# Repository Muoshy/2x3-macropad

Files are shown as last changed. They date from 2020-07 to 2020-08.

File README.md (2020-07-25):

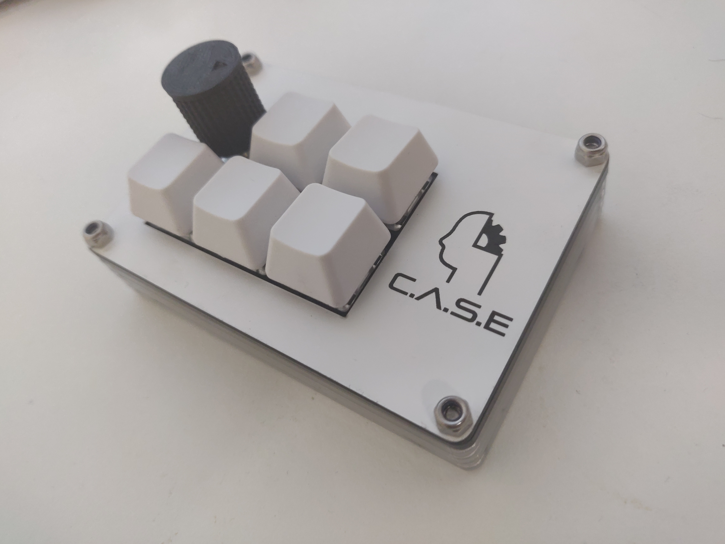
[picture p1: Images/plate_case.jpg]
top


# 2x3 Macropad

Extremely simple 2x3 macropad with sandwich case.

  - QMK firmware
  - Acrylic sandwich case
  - Encoder support
  
## Schematic

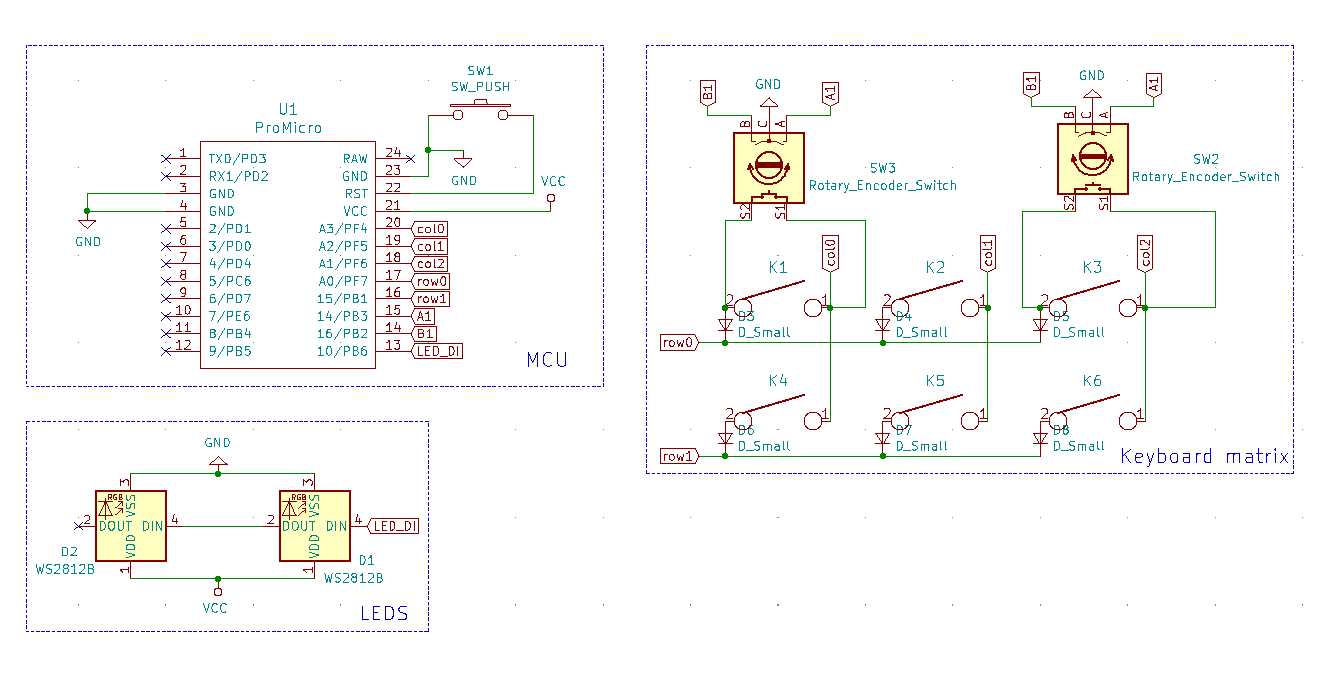
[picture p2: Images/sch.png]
sch


## PCB

## Case
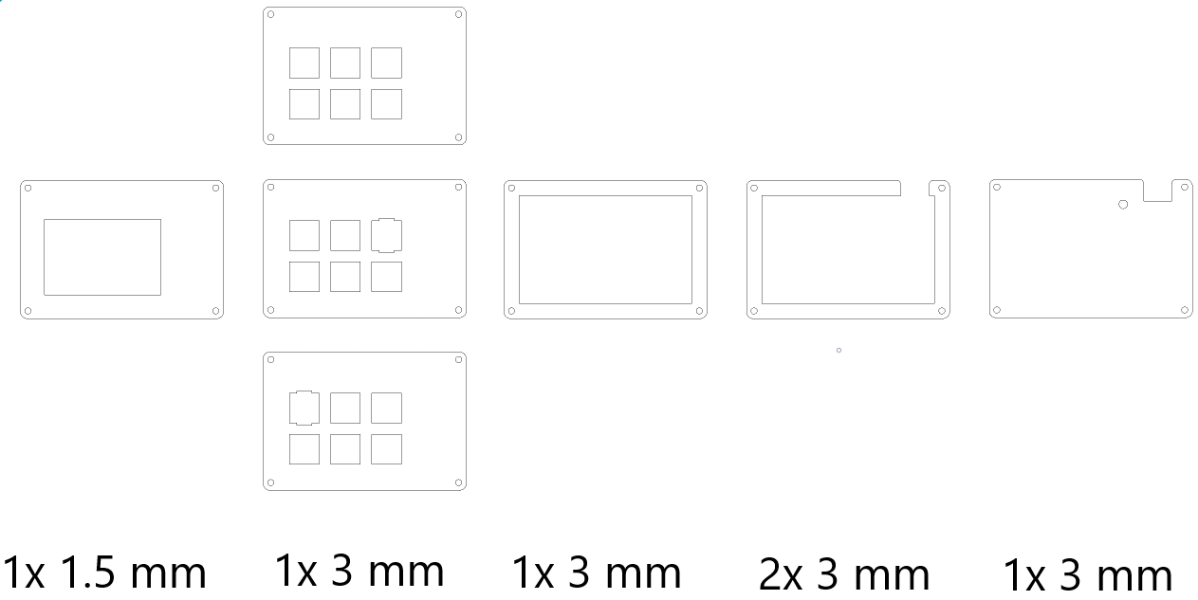
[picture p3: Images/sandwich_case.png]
case

Case plates for laser cutting. 0.15 mm kerf already accounted for in .dxf files.
Choose one of the three switch plates according to your encoder placement. 
For same results as image above, engrave on 2 layer acrylic.

  - 4x M3 20mm screws
  - 4x M3 nuts

## Software
Running on QMK firmware. Use QMK Toolbox to flash with provided HEX file.
Then use VIA configurator to configure keybinds.
For further customization (encoder keycodes), setup a QMK build environment and compile your own HEX files.

## Flashing
  - Download and open QMK Toolbox
  - Select HEX file
  - Choose ATMega32u4 as microcontroller
  - Push reset button on board and then press flash button in toolbox.

## Keybinds
  - Download and install VIA Configurator
  - Open VIA and go to File->Import Keymap
  - Select the keymap.json file
  - Plug in the macropad

## BOM

| Component 		| Quantity 	| Link 								|
|---		|---	|---								|
| MX switches 		| 6x (5x) | 								|
| 1N4148 diodes 		| 6x 	| 								|
| 5.2x5.2mm SMD pushbutton 		| 1x 	| [Mouser](https://www.google.com) 	|
| Arduino Pro Micro 5V 16 MHz | 1x 	| 								|
| WS2812B 		| 2x 	| 								|
| EC11 Encoder 15mm shaft 	| 1x 	| 								|

WS2812B optional as undeglow is not the best on this board due to few LEDs and bad placement.
Only 5 switches needed if also using encoder.

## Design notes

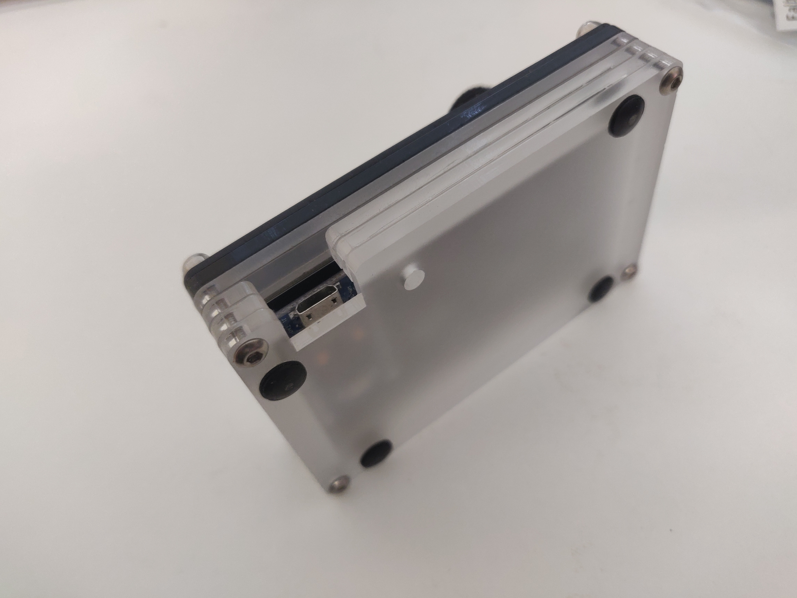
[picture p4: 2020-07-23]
Images/side_view.jpg

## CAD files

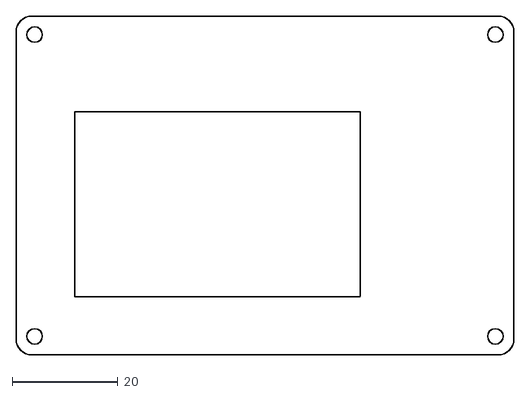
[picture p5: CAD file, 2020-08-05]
Hardware/Sandwich case/#top_plate_engraving.dxf
94.0 x 64.0

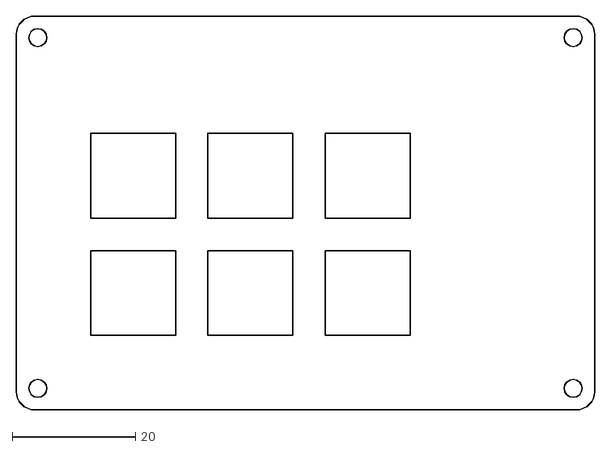
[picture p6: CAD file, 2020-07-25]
Hardware/Sandwich case/switch_plate_no_encoder.dxf
94.0 x 64.0

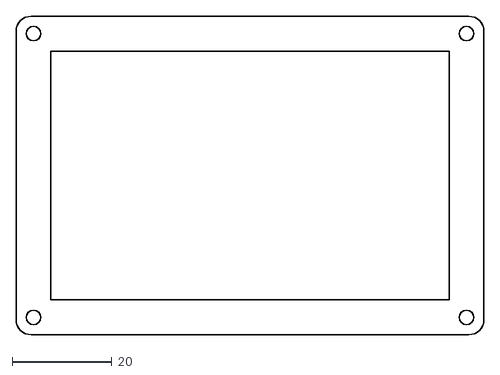
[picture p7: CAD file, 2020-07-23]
Hardware/Sandwich case/middle_plate.dxf
94.0 x 64.0

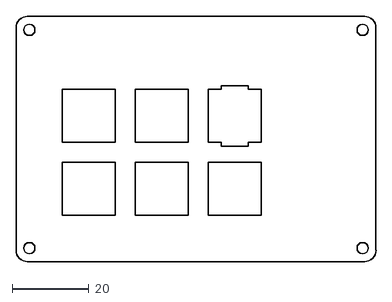
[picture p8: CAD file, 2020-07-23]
Hardware/Sandwich case/switch_plate_right_encoder.dxf
94.0 x 64.0

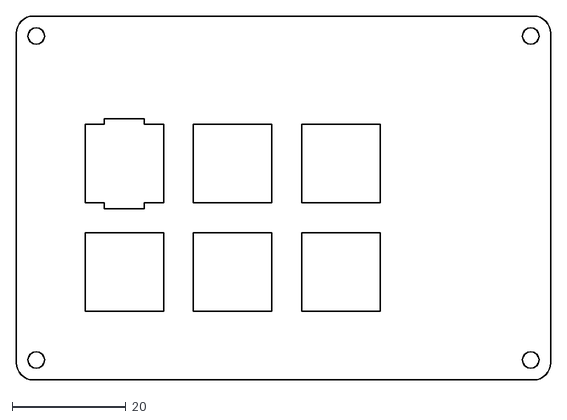
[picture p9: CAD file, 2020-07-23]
Hardware/Sandwich case/switch_plate_left_encoder.dxf
94.0 x 64.0

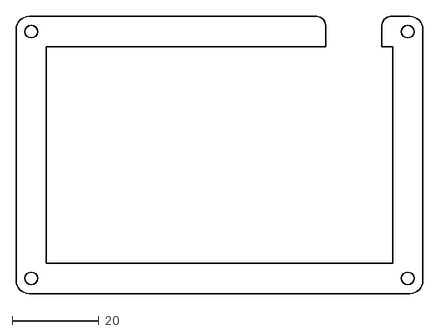
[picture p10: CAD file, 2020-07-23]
Hardware/Sandwich case/middle_plate_cutout.dxf
94.0 x 64.0

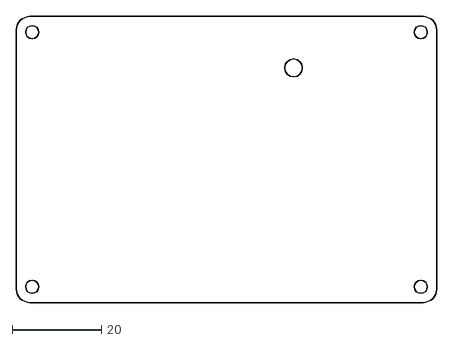
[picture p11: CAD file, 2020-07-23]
Hardware/Sandwich case/bottom_plate.dxf
94.0 x 64.0

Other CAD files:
Hardware/Sandwich case/top_plate_engraving.dxf

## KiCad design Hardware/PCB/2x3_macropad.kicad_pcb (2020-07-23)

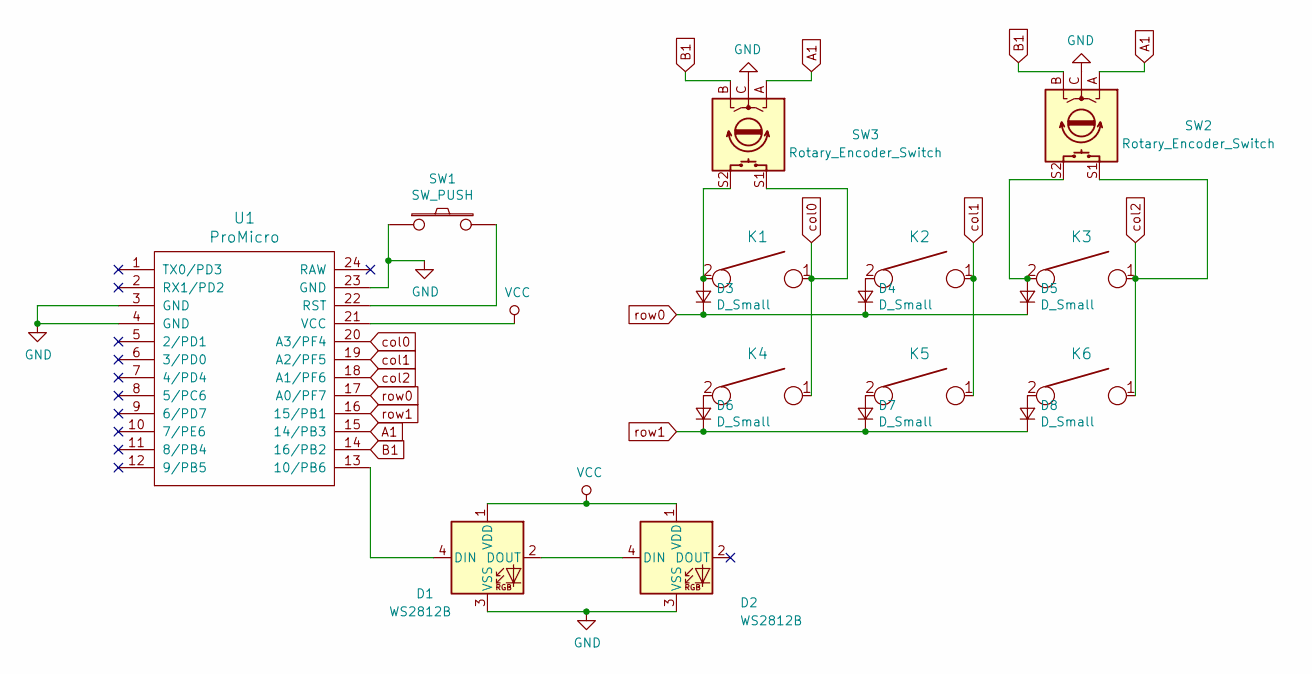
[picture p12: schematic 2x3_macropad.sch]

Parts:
D1, D2: WS2812B; LED_WS2812B_PLCC4_5.0x5.0mm_P3.2mm
D3, D4, D5, D6, D7, D8: D_Small; Diode-dual
K1, K2, K3, K4, K5, K6: KEYSW; MX_PCB_100H
SW1: SW_PUSH; SW_PTS525SM15SMTR2LFS
SW2, SW3: Rotary_Encoder_Switch; RotaryEncoder_Alps_EC11E-Switch_Vertical_H20mm
U1: ProMicro; ArduinoProMicro

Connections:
A1: SW2.A, SW3.A, U1.15 (14/PB3)
B1: SW2.B, SW3.B, U1.14 (16/PB2)
GND: D1.3 (VSS), D2.3 (VSS), SW1.1, SW2.C, SW3.C, U1.3 (GND), U1.4 (GND), U1.23 (GND)
unnamed: D1.2 (DOUT), D2.4 (DIN)
unnamed: D1.4 (DIN), U1.13 (10/PB6)
unnamed: D3.2 (A), K1.2, SW3.S2
unnamed: D4.2 (A), K2.2
unnamed: D5.2 (A), K3.2, SW2.S2
unnamed: D6.2 (A), K4.2
unnamed: D7.2 (A), K5.2
unnamed: D8.2 (A), K6.2
unnamed: SW1.2, U1.22 (RST)
VCC: D1.1 (VDD), D2.1 (VDD), U1.21 (VCC)
col0: K1.1, K4.1, SW3.S1, U1.20 (A3/PF4)
col1: K2.1, K5.1, U1.19 (A2/PF5)
col2: K3.1, K6.1, SW2.S1, U1.18 (A1/PF6)
row0: D3.1 (K), D4.1 (K), D5.1 (K), U1.17 (A0/PF7)
row1: D6.1 (K), D7.1 (K), D8.1 (K), U1.16 (15/PB1)

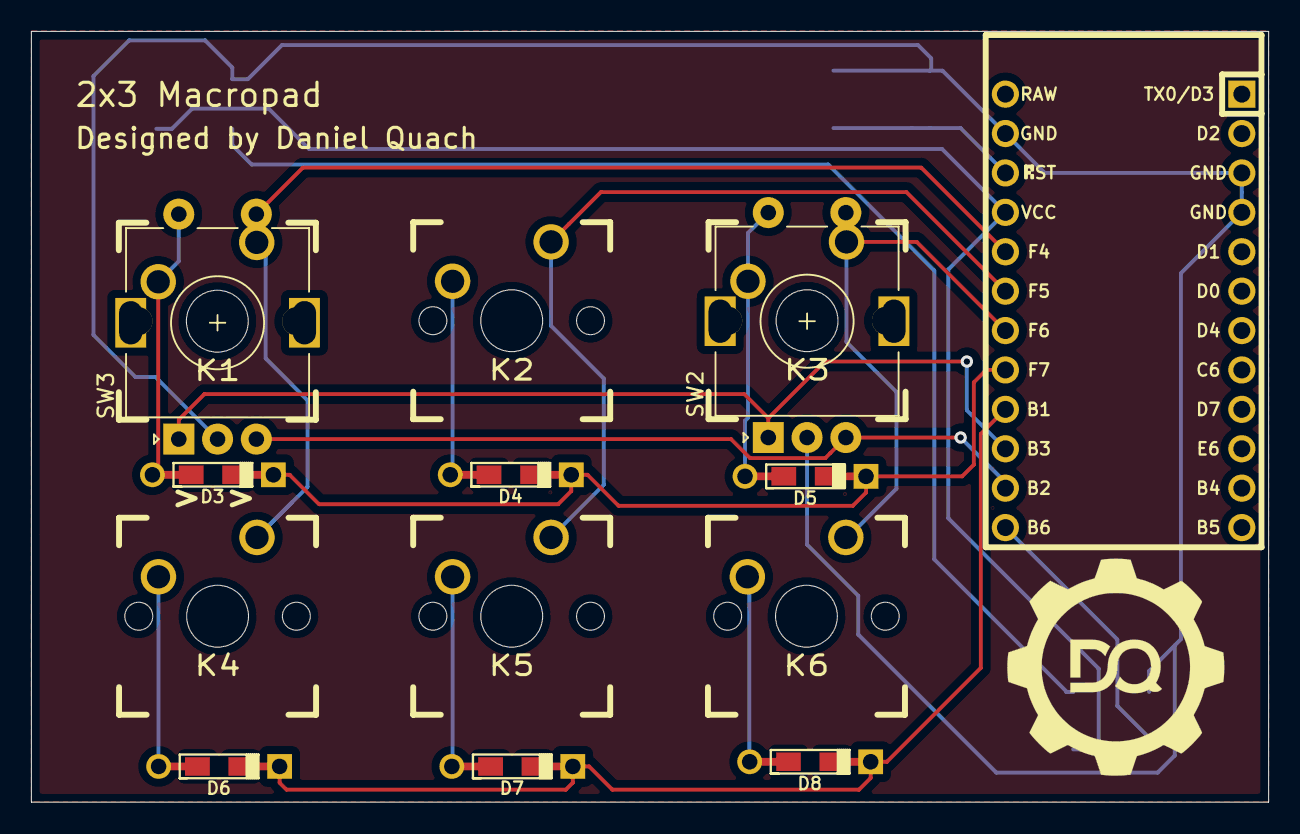
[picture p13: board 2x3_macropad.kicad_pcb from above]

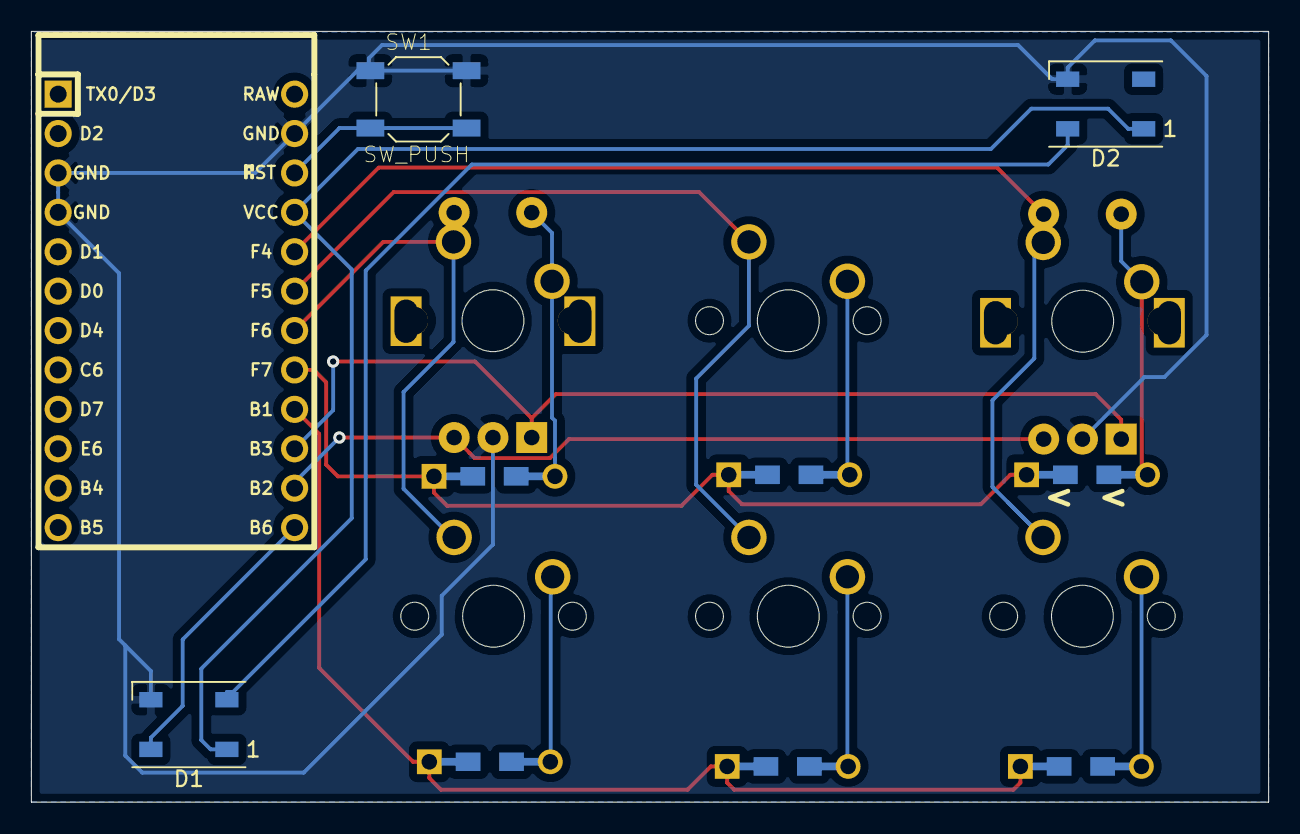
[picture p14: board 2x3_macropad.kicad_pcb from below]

Board: 2 copper layers, 79.8 x 49.7 mm, 18 parts (4 on the bottom side), 18 nets.

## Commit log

2020-07-23 added hardware
    [2x3_macropad-B_Cu.gbl, 2x3_macropad-B_Mask.gbs, 2x3_macropad-B_Paste.gbp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]
2020-07-25 case fixes
    [top_plate_engraving.dxf]
2020-07-25 schematic fixes
    [2x3_macropad.sch]
2020-07-25 renamed plate files
    [middle_plate.dxf, middle_plate_cutout.dxf]
2020-07-25 case changes
    [top_plate_no_encoder.dxf]
